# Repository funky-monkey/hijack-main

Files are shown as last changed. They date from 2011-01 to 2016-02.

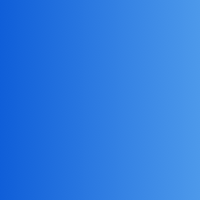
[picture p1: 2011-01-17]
iPhone/EKGmon/core-plot/systemtests/tests/TestResources/CPGradientTests-testDrawSwatchRendersCorrectlyForFactoryGradients-sourceListSelectedGradient.tiff

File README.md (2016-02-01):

# hijack-main
(Imported from https://hijack-main.googlecode.com/svn/ )

Hijacking power and bandwidth from the mobile phone's audio interface. Creating a cubic-inch peripheral sensor ecosystem for the mobile phone.

HiJack is a hardware/software platform for creating cubic-inch sensor peripherals for the mobile phone. HiJack devices harvest power and use bandwidth from the mobile phone's headset interface. The HiJack platform enables a new class of small and cheap phone-centric sensor peripherals that support plug-and-play operation.

See the Project Homepage for more details: http://www.eecs.umich.edu/~prabal/projects/hijack/

HiJack is a hardware/software platform for creating cubic-inch sensor peripherals for the mobile phone. HiJack devices harvest power and use bandwidth from the mobile phone's headset interface. The HiJack platform enables a new class of small and cheap phone-centric sensor peripherals that support plug-and-play operation. HiJack has been tested with the iPhone 3G/3GS/4G, iPod Touch, and iPad devices.

Power. The HiJack energy harvester can supply 7.4 mW to a load with 47% power conversion efficiency when driven by a 22 kHz tone from the output from a single audio channel on the iPhone 3GS headset port, all using electronic components that cost just $2.34 in 10K volumes. We are exploring other approaches for achieving higher conversion efficiencies.

Data. The HiJack communications layer offers two data transfer schemes. The first allows 300 baud data transfer using Bell 202 FSK signaling. The second offers 8.82 kbaud using a Manchester-encoded, direct-digital communication using hardware accelerators on the HiJack microcontroller and a software-defined, digital radio modulator/demodulator on the phone. The first scheme is described in the ISLPED'10 Design Contest entry (below). The second scheme is described in the DEV'10 paper below.

Sensing. We envision a range of sensorboards including ozone, carbon monoxide, DVM, blood pressure, blood glucose, and others. But today, we only have four daughterboards: (1) a simple demo board with temperature/humidity sensors, PIR motion sensor, and potentiometer used on the early HiJack prototypes; (2) a 3-lead EKG sensor; (3) a basic soil moisture sensor; (4) a breakout board for fast prototyping on the latest generation of HiJacks. 

Wendell Capili wrote a really nice tutorial on libHiJack. You can find the 3 parts here:

    http://wendellinfinity.wordpress.com/2011/08/21/hijack-in-the-box-part-1/
    http://wendellinfinity.wordpress.com/2011/08/21/hijack-in-the-box-part-2/
    http://wendellinfinity.wordpress.com/2011/08/21/hijack-in-the-box-part-3/

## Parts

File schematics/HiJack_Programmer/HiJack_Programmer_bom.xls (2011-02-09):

Qty | Value | Device | Parts | Manufacturer | Manufacturer Part Number | Supplier | Supplier Part Number | Cost (1u) | Comment
2 | 0.01uF | CAPACITOR1608 | C1, C3 | AVX | 06035C103KAT2A | digikey.com | 478-1227-1-ND
6 | 0.1uF | CAPACITOR1608 | C2, C4, C5, C6, C7, C24 | Murata |  | digikey.com | 490-1524-1-ND
2 | 0.01uF | CAPACITOR1608 | C1, C3 | Panasonic | ECJ-1VB1H103K | digikey.com | PCC1784CT-ND | 0.042 | 50V, 10%, X7R | obsolete
6 | 0.1uF | CAPACITOR1608 | C2, C4, C5, C6, C7, C24 | Panasonic | ECJ-1VB1E104K | digikey.com | PCC2277CT-ND | 0.042 | 25V, 10%, X7R | obsolete
1 | 1k |  | R4 | Rohm | MCR03EZPJ102 | digikey.com | RHM1.0KGCT-ND | 0.071 | 0.1W, 5%, Thick Film
1 | 1k | RESISTOR1608 | R4 | Yageo | RC0603JR-071KL | digikey.com | 311-1.0KGRCT-ND | 0.064 | 0.1W, 5%, Thick Film | not in stock
1 | 4.7uF | CAP_POL1206 | C34 | Kemet | B45196H3475K109 | digikey.com | 495-2232-1-ND | 0.21 | 16V, 10%, 4.000 Ohm ESR
1 | 10K | RESISTOR1608 | R2 | Yageo | RC0603JR-0710KL | digikey.com | 311-10KGRCT-ND | 0.064 | 0.1W, 5%, Thick Film
3 | 100 | RESISTOR1608 | R1, R3, R5 | Panasonic | ERJ-3GEYJ101V | digikey.com | P100GCT-ND | 0.071 | 0.1W, 5%, Metal Film
1 | 11029 | ARDUINO_SERIAL_PROGRAMSMD | JP1 | 4UCON Technology | 11029 | sparkfun.com | PRT-09015 | 0.95 | (also available at http://www.4uconnector.com/)
DNP | CDBU0240 | SCHOTTKY-DIODE0603 | D3 | Comchip Technology | CDBU0240 | digikey.com | 641-1009-1-ND | 0.46 | Schottky, 40V, 550mV@200mA, 10uA@30V reverse leakage, 9pF@10V
3 | FIDUCIAL1X2 | FIDUCIAL1X2 | U$2, U$3, U$4
1 | FLYING_CAMP_DESIGN_LOGO | FLYING_CAMP_DESIGN_LOGO | U$1
1 | FT232RL | FT232RL | U3 | FTDI | FT232RL | digikey.com | 768-1007-1-ND | 4.5 | 3.3V-5.25V
1 | Ferrite Bead | INDUCTOR0603 | L1 | Steward | MI0603K300R-10 | digikey.com | 240-2373-1-ND | 0.081 | 1.5A, 100MHz, 30 Ohm
1 | GREEN | LED1608 | D4 | Rohm | SML-310PTT86 | digikey.com | 511-1300-1-ND | 0.3 | 4mcd, 2.2V, 555nm, 555nm, 20mA, 140 deg, Clear, 17mlm
1 | MIC2025/SOIC-8 | MIC2025/SOIC-8 | U1 | Micrel | MIC2025-2YM | digikey.com | 576-1058-ND | $1.18 | 140m Ohm Rds(on), 10mA Leakage
1 | MOLEX_48037-1000 | MOLEX_48037-1000 | P1 | Molex | 48037-1000 | digikey.com | WM17118-ND | 2.22 | Plug, USB-A, Shielded
2 | PGB102ST23 | LITTELFUSE_PGB102ST23 | F3, F4 | Littelfuse | PGB102ST23WR | digikey.com | F2596CT-ND | 1.5 | Bidirectional, 24V Reverse Standoff Voltage
2 | PGB1010603 | LITTELFUSE_PGB1010603 | F1, F2 | Littelfuse | PGB1010603MR | digikey.com | F2594CT-ND | 0.86 | Bidirectional, 24V Reverse Standoff Voltage
1 | RED | LED1608 | D2 | Rohm | SML-310VTT86 | digikey.com | 511-1301-1-ND | 0.3 | 4mcd, 2.0V, 630nm, 630nm, 20mA, 140 deg, Clear, 17mlm
1 | TPS73633DBVT | TPS73633DBVT | U4 | Texas Instruments | TPS73633DBVT | digikey.com | 296-15819-1-ND | 3.15 | IC LDO REG 400MA 3.3V SOT23-5
1 | YELLOW | LED1608 | D5 | Rohm | SML-310YTT86 | digikey.com | 511-1302-1-ND | 0.3 | 6.3mcd, 2.1V, 585nm, 585nm, 20mA, 140 deg, Clear, 26mlm

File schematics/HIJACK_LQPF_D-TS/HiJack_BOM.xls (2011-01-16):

Part | Remark | Value | Device | Package | Description | Distributor | Distrib. Part Number
C1, C3 |  | 0.1 uF | C0603 | 0603-CAP | Capacitor | DigiKey | 490-1524-6-ND
C2 |  | 4.7nF | C0603 | 0603-CAP | Capacitor | DigiKey | 490-1506-6-ND
C6, C8 |  | 2.2u | C0603 | 0603-CAP | >16V | DigiKey | 490-3296-6-ND
C9, C10 |  | 10uF | C0603 | 0603-CAP | Capacitor | DigiKey | 490-3896-6-ND
C4, C5 |  | 1uF | C0603 | 0603-CAP | >16V | DigiKey | 490-3897-6-ND
C7 |  | 100uF | C0603 | 0603-CAP | >16V | DigiKey | 399-5214-6-ND
D1 |  | DIODE | DIODE | MINIMELF | Shotkey Diode | DigiKey | 568-3423-6-ND
D2 | DNP |  | LED0603 | LED-0603 | LEDs | DigiKey | 475-2816-6-ND
J1 |  | 3.5JACK4CONN | 3.5JACK4 | PLUGBOARDCONNECTOR | Headset Jack | Mouser | 171-7435-EX
J2, J3, J4 |  | HEADER10POS | HEADER10POS | 10PIN2MMHEADER | Fits 3M 950510-6102-AR | DigiKey | 3M9405-ND
Q1, Q2 |  |  | NMOSSOT23 | SOT-23 | MOS FET | DigiKey | ZXM61N03FDKR-ND
Q3, Q4 |  |  | PMOSSOT23 | SOT-23 | MOS FET | DigiKey | ZXM61P03FDKR-ND
R1, R2, R6 |  | 100k | RESISTOR0603-RES | 0603-RES | Resistor | DigiKey | RHM100KGDKR-ND
R3 |  | 10k | RESISTOR0603-RES | 0603-RES | Resistor | DigiKey | RHM10KGDKR-ND
R4 |  | 100k 0.1% | RESISTOR0603-RES | 0603-RES | Resistor | DigiKey | CRT0603-BY-1003ELFDKR-ND
R5 |  | 5.1M | RESISTOR0603-RES | 0603-RES | Resistor | DigiKey | RHM5.1MGDKR-ND
R8 |  | 698 | RESISTOR0603-RES | 0603-RES | Resistor | DigiKey | RHM698HDKR-ND
R9 |  | 1k | RESISTOR0603-RES | 0603-RES | Resistor | DigiKey | RHM1.00KHDKR-ND
R10, R12, R13 |  | 3M | RESISTOR0603-RES | 0603-RES | Resistor | DigiKey | RHM3.0MGDKR-ND
R11 |  | 1M | RESISTOR0603-RES | 0603-RES | Resistor | DigiKey | RHM1.0MGDKR-ND
T1 |  | LPR6235 | LPR6235 | LPR6235 | Transformer | Coilcraft | LPR6235-253PMLB
U1 |  | MSP430F1611IPM | MSP430F1611IPM | PM/PAG64 | MCU | DigiKey | 296-17205-ND
U3 |  | MIC5231 | MIC5231 | SOT23-5 | LDO | DigiKey | 576-2771-6-ND
Y1 |  | ABS07-32.768KHZ-7-T | ABS07-32.768KHZ-7-T | ABS07-32.768KHZ-7-T | Crystal | DigiKey | 535-9543-6-ND
Do not populate red marked items!

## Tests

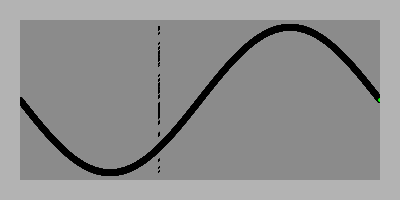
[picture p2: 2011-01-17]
iPhone/EKGmon/core-plot/systemtests/tests/TestResources/CPXYGraphTests-testRenderStressTest.ppc.tiff

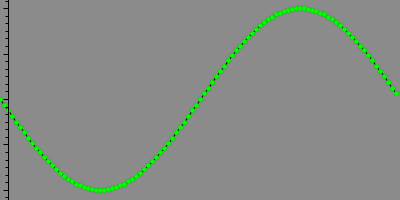
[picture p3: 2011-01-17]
iPhone/EKGmon/core-plot/systemtests/tests/TestResources/CPXYGraphTests-testRenderScatterWithSymbol.tiff

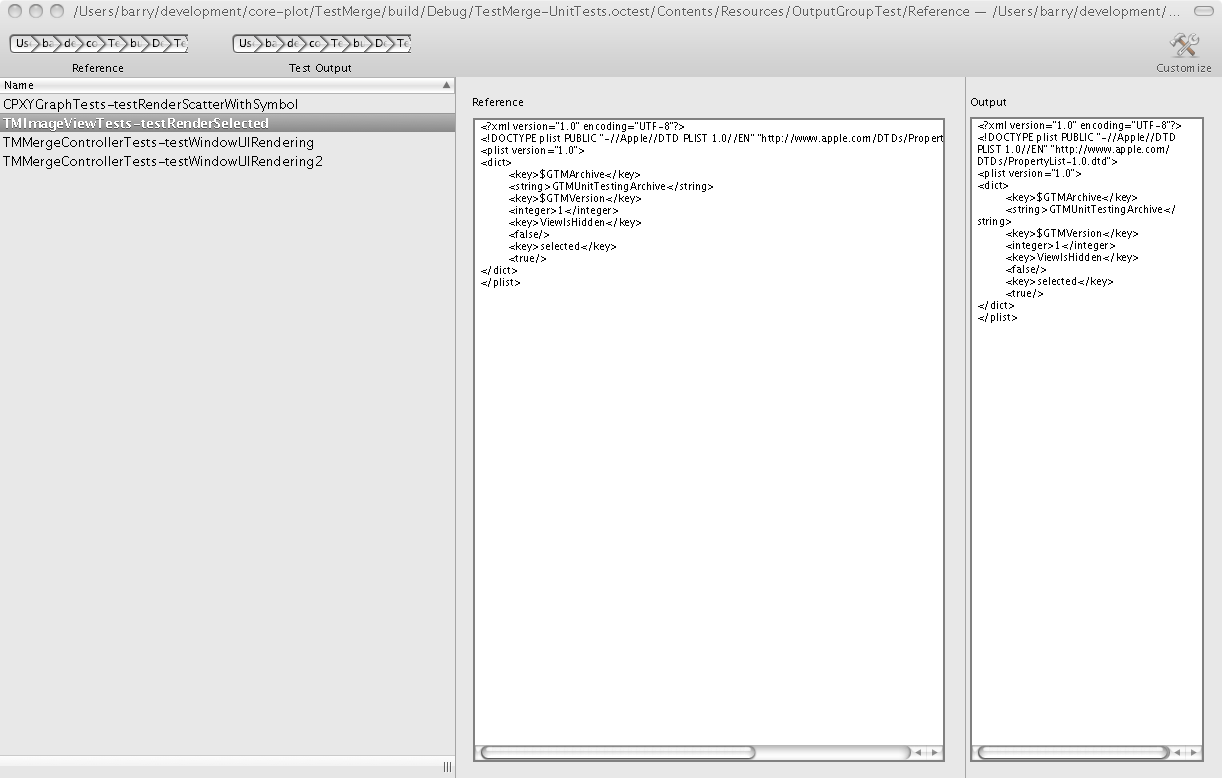
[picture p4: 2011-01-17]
iPhone/EKGmon/core-plot/TestMerge/TestResources/TMMergeControllerTests-testSelectsAndRendersUTStateCompareController+DoNotReplaceReference.tiff

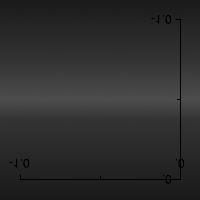
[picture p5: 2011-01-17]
iPhone/EKGmon/core-plot/systemtests/tests/TestResources/CPDarkGradientThemeTests-testApplyThemeToBackground.tiff

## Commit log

2011-01-14 adding schematics
    [HIJACK_LQPF_D.GBL, HIJACK_LQPF_D.GBO, HIJACK_LQPF_D.GBP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]
2011-01-16 Adding BOM
    [HiJack_BOM.xls]
2011-01-17 Added EKGmon app - an EKG interface on the iPhone that uses the hijack interface for EKG leads
    [piezoresonance.csv, xcconfigs-readme.txt]
2011-02-09 Adding HiJack Programmer and Proto-Typing boards schematics
    [HiJack_Programmer.GBL, HiJack_Programmer.GBO, HiJack_Programmer.GBP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]
2011-02-09 Adding example for a HiJack UART0 pass-through.
2011-02-09 Updating schematics
    [HiJack_Programmer.brd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]
2011-08-08 Adding LibHiJack
    LibHiJack can be used to write your own application that interfaces with a HiJack device. It contains the core processing and communication parts from the oscilloscope application, without all the gr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
